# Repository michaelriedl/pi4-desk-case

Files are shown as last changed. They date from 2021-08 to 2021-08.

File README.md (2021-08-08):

# Raspberry Pi 4 Desk Case
I wanted to have a Raspberry Pi 4 on my desk to run various tasks and also wanted to have active cooling for it. I came across the *GeeekPi Raspberry Pi 4 Fan* on Amazon and loved how overkill it looked/seemed. I decided to order the cooler and design a 3D printed case to fit around it all. The Pi 4 with the cooler attached is pictured below.

<p align="center">
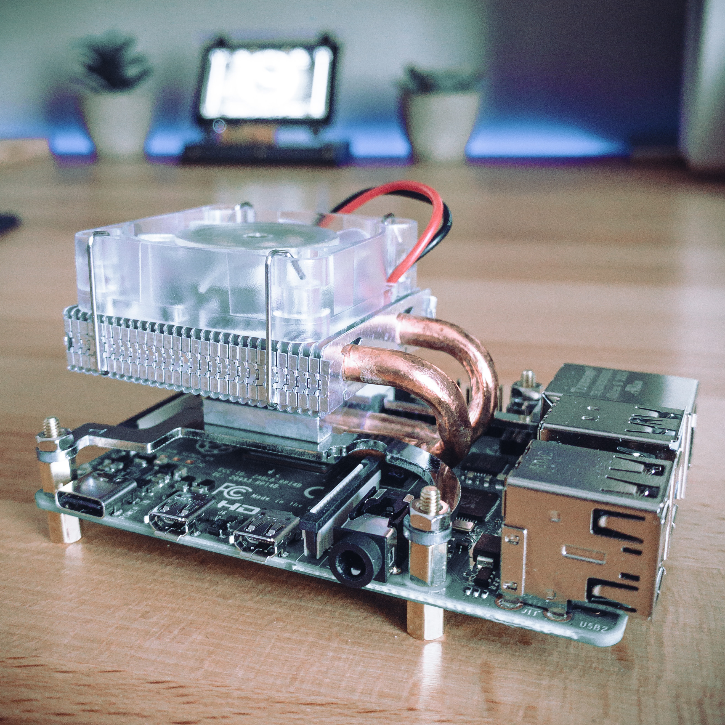
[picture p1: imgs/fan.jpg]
fan
  
</p>

## Parts
Here, the parts needed will be briefly outlined. Some parts will have links; others you will need to find sources for.

Brass standoffs are included with the *GeeekPi Raspberry Pi 4 Fan* to mount the cooler to the Pi. The case uses these standoffs to mount the Pi to the 3D printed plate that slides in and out of the case.

M3 brass threaded inserts and screws are used to assemble the case. The parts are linked below:
+ <https://www.mcmaster.com/94180A331>
+ <https://www.mcmaster.com/93070A064>

The vents of the case are designed to be glued into the panels. Therefore, some type of adhesive will be needed that is appropriate for bonding the type of filament used to print the case. Hot glue will work but may be difficult to work with. I used E6000 and it was easy to use and has held up well over time.

The case is also designed to have rubber feet to reduce fan vibration from transferring to the desk it will sit on. I bought the feet from Amazon and are called *VOVOV Self-Adhesive Clear Rubber Feet Tiny Bumpons 0.25" in Diameter x 0.079" Height*.

## Printing
The individual STL files are provided if pieces need to be printed individually or laid out differently for various sized print beds. There are also three files that have the parts grouped by case and vents so that parts that are likely to have the same color can be printed at the same time. These files are as follows:
  1. "Case - All pt1.stl"
  2. "Case - All pt2.stl"
  3. "Vents - All.stl"

Some of these parts may need to be printed with support material from the build plate if your printer does not print small overhangs well.

## Assembly
The case can be assembled in a few simple steps. 
  1. Attach the Pi 4 to the 3D printed mounting plate. Use the extra screws included with the cooler.
  2. Insert the threaded brass inserts with a soldering iron. There are guides to this process online. There are very tight tolerances around the inserts so be careful to make sure they are inserted squarely and do not shift. Using the lowest amount of heat possible can help with this.
  3. Adhere the vents to the panels and snap the port plate over the power, HDMI, and audio ports.
  4. Snap together the front, back, top, and bottom panels. Again, the tolerances are very tight so some sanding may be necessary, especially if support material is used for some of the parts.
  5. Slide the Pi 4 into the case and screw on the right and left panels. The M3 screws should end up flush with the sides of the case.
  6. Add the rubber feet to the bottom of the case.

These images may be helpful for reference during assembly. 

<p align="center">
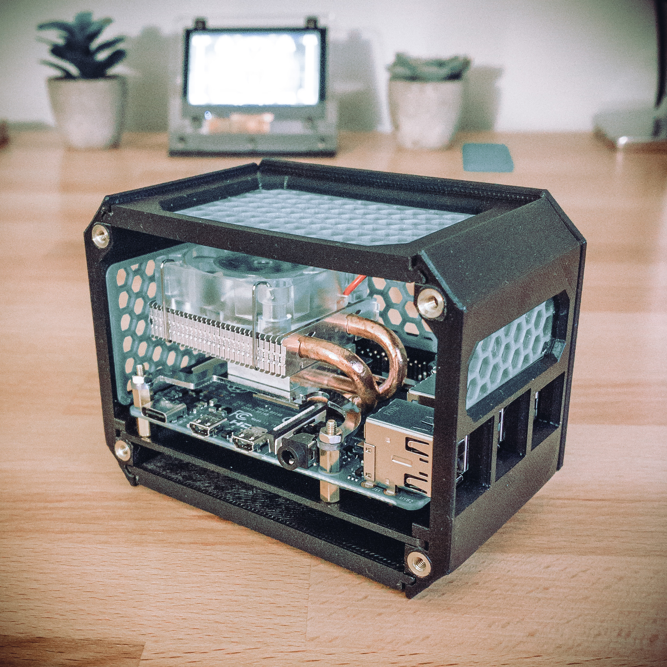
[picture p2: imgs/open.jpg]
open
  
</p>

<p align="center">
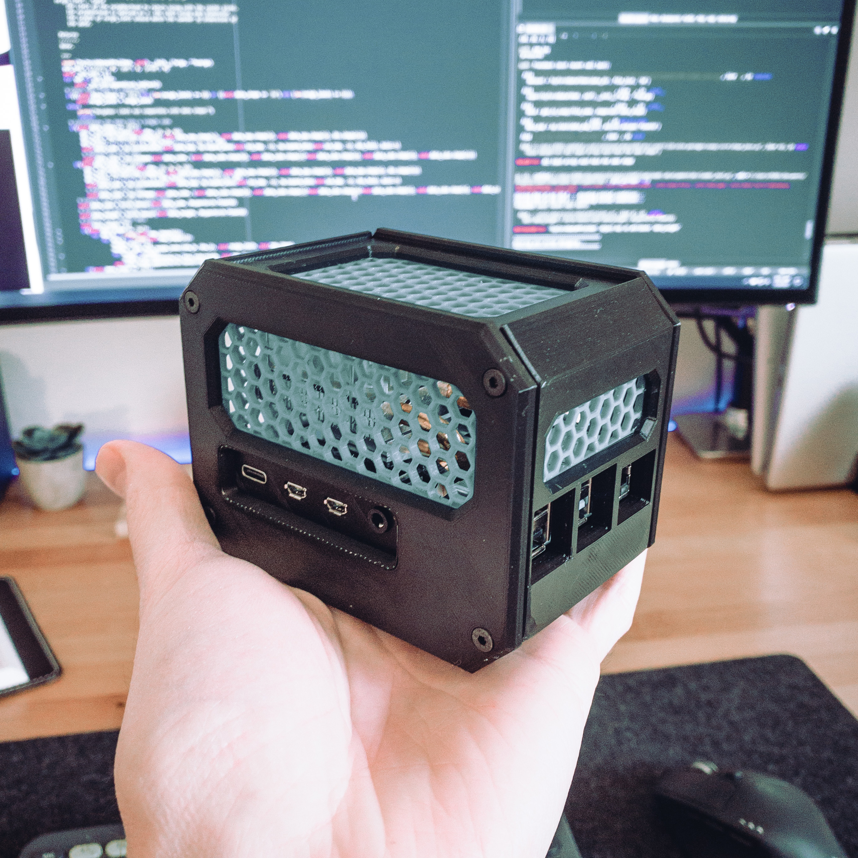
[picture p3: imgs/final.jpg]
final
  
</p>

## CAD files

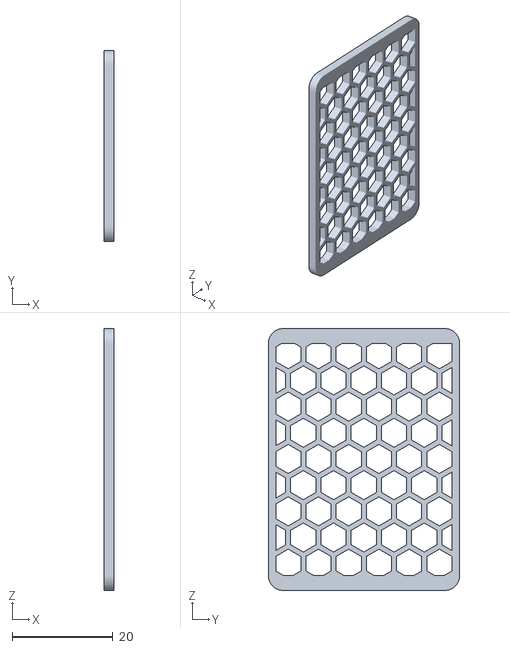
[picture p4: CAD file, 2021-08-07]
stl/Vent - Back.stl
2.00 x 38.0 x 52.0

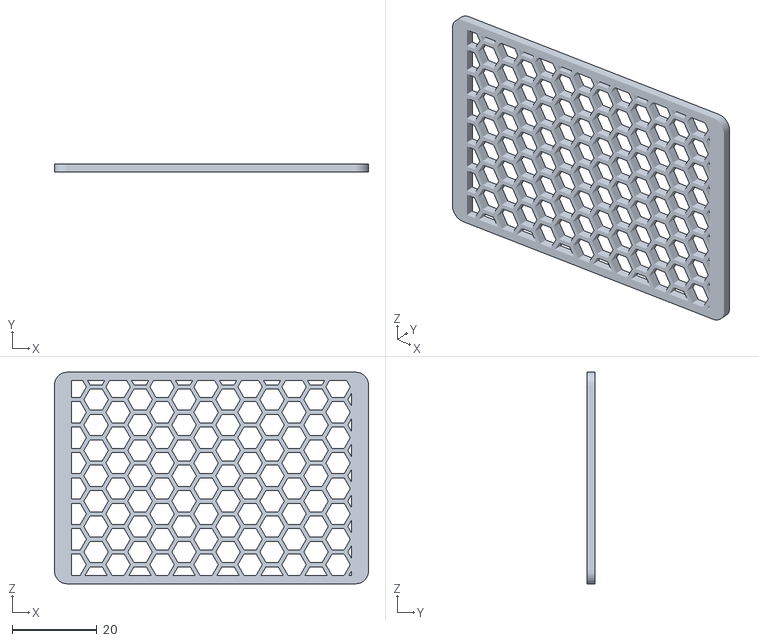
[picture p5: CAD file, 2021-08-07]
stl/Vent - Top.stl
74.2 x 2.00 x 50.0

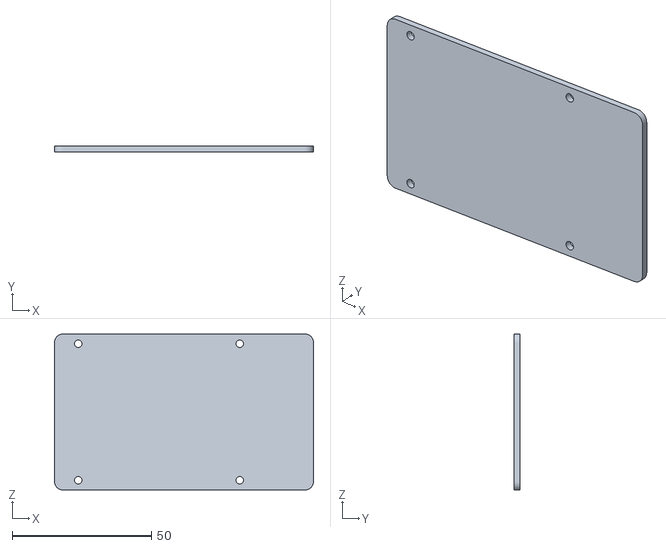
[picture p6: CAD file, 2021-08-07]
stl/Pi4 Base.stl
93.0 x 2.00 x 56.0

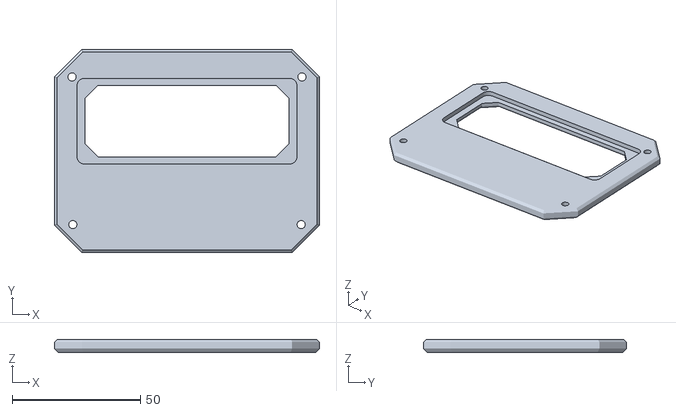
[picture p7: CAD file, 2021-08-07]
stl/Case - Left.stl
103.5 x 79.3 x 5.00

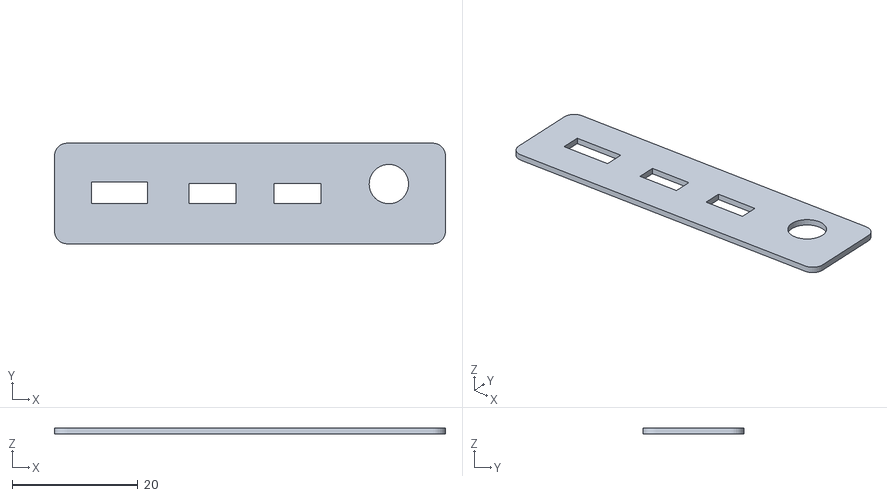
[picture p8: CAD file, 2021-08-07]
stl/Port Plate.stl
62.1 x 16.0 x 1.00

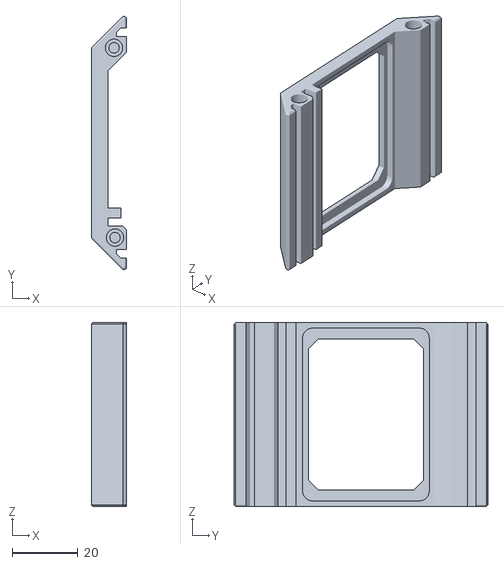
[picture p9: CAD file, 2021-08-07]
stl/Case - Back.stl
10.7 x 77.2 x 56.0

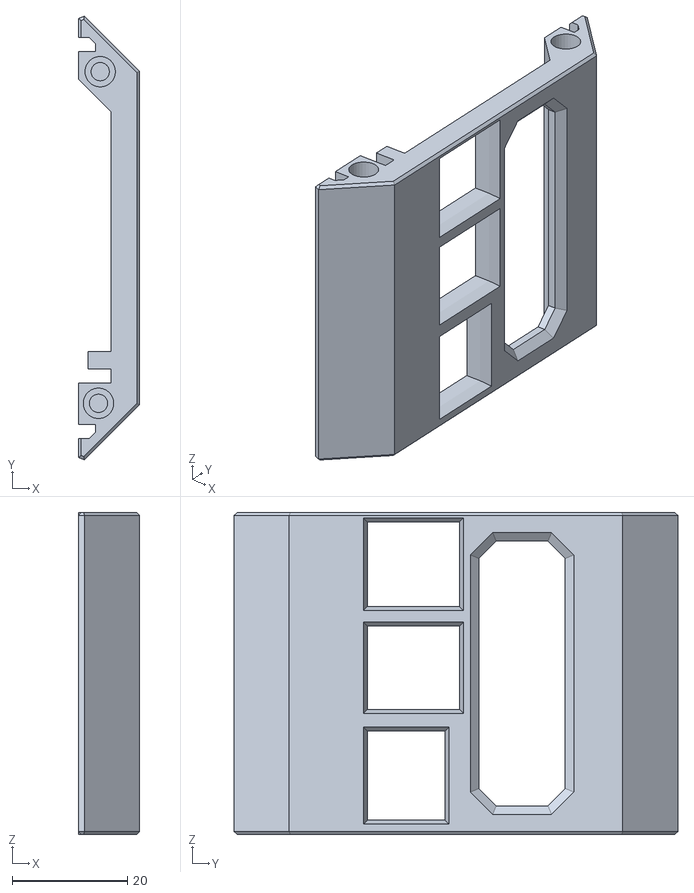
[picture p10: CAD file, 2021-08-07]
stl/Case - Front.stl
10.7 x 77.2 x 56.0

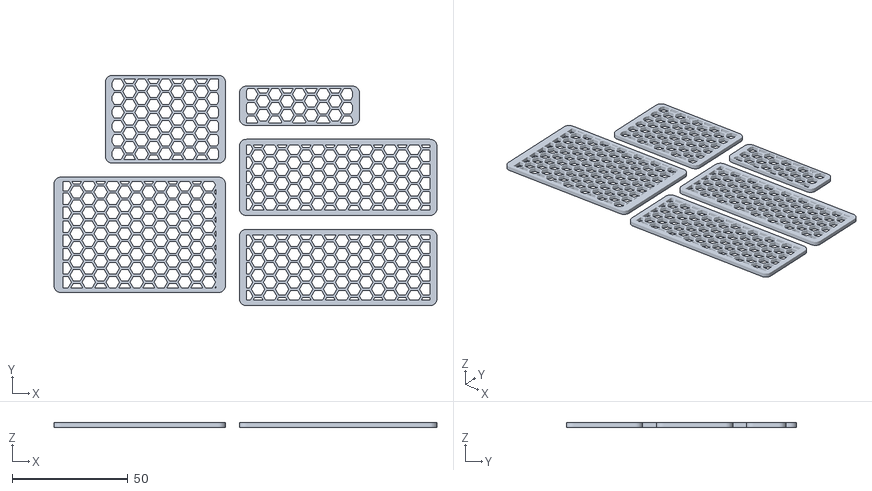
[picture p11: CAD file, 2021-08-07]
stl/Vents - All.stl
165.7 x 99.7 x 2.00

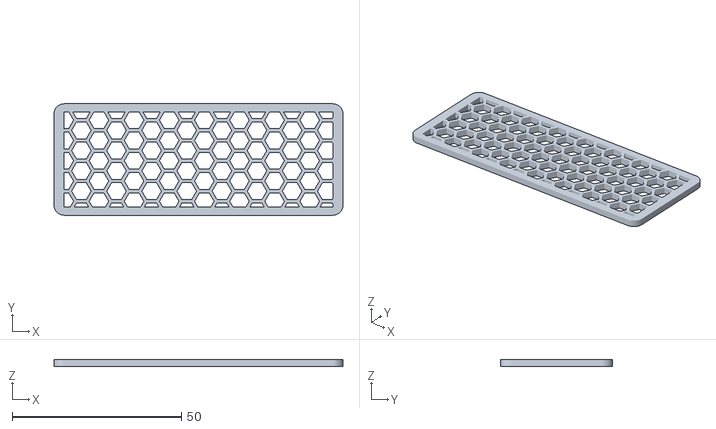
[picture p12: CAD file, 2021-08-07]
stl/Vent - Left.stl
85.5 x 33.0 x 2.00

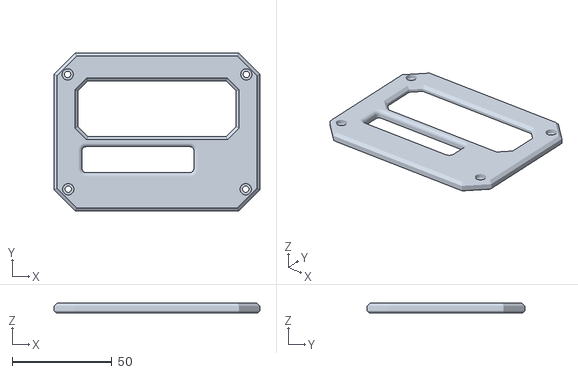
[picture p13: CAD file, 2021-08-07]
stl/Case - Right.stl
103.5 x 79.3 x 5.00

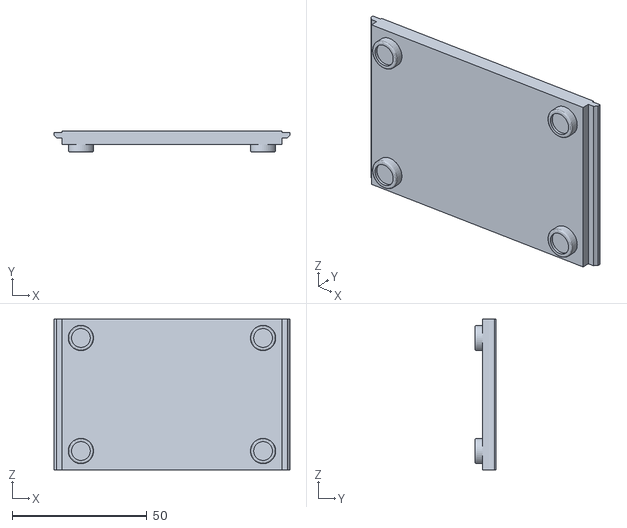
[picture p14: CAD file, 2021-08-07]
stl/Case - Bottom.stl
87.7 x 7.75 x 56.0

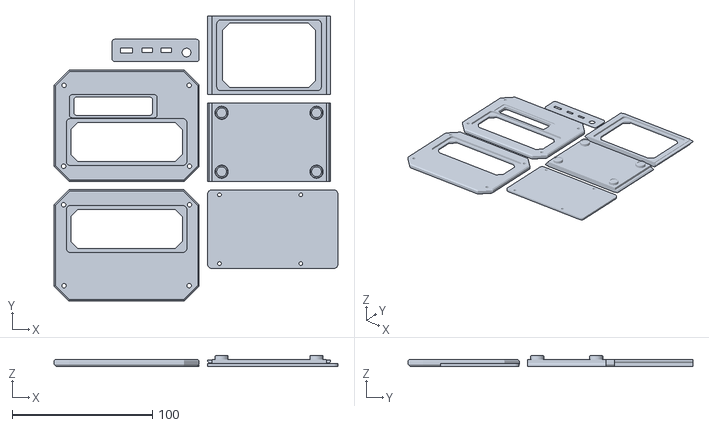
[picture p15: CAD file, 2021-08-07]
stl/Case - All pt1.stl
202.5 x 203.2 x 7.75

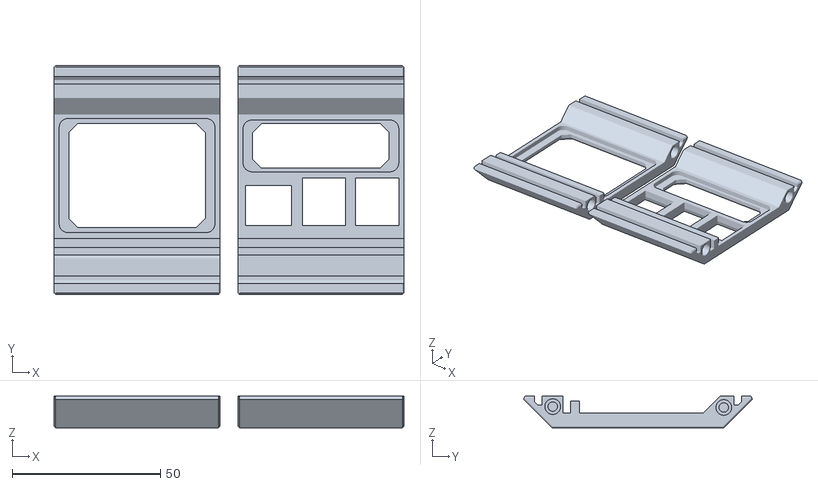
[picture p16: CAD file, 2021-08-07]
stl/Case - All pt2.stl
118.0 x 77.2 x 10.7

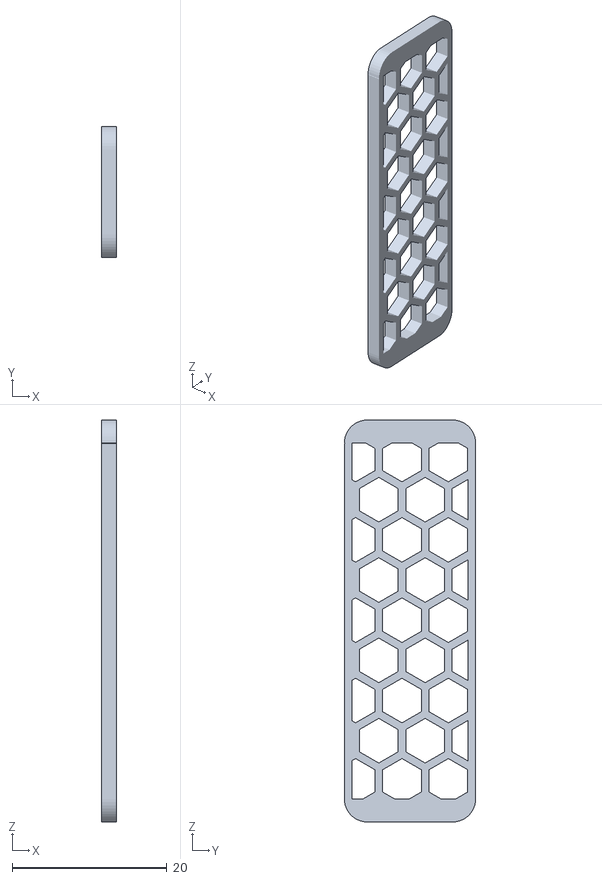
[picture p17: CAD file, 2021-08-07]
stl/Vent - Front.stl
2.00 x 17.0 x 52.0

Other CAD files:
stl/Vent - Right.stl
stl/Case - Top.stl
